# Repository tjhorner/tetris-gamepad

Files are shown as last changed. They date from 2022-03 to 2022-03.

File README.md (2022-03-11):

# Tetris Gamepad

These are the source files for an arcade-style gamepad designed for Tetris gameplay. Work in progress (things will break!)

**Disclaimer**: Tetris is a trademark of The Tetris Company, and I am not affiliated in any way with them. I'm just a fan of the game, and wanted to make this cool project for fun (and not profit). If you're a TTC lawyer and want me to rename this project, just let me know and I'll gladly do so. (No need to DMCA 😛)



## Directory Structure

- `src`: Source files for the firmware (licensed under MIT)
- `design`: PCB and enclosure design files (licensed under CC-BY-SA 4.0)
  - **Note:** The KiCad files may require you to install the [DigiKey library](https://forum.digikey.com/t/importing-the-digi-key-kicad-library-into-kicad-5-0-0/4075)

## Hardware

**License:** CC-BY-SA 4.0

This project is intended to be used with the [Adafruit HUZZAH32](https://www.adafruit.com/product/3405) board (mostly because that's what I had lying around), but with minor tweaks could be modified to use any ESP32 board, or even a raw ESP32 chip. The design is pretty simple; it just uses the GPIO pins in either `INPUT_PULLUP` mode (for the button inputs) or `OUTPUT` mode (for the button LEDs). Since it uses the `INPUT_PULLUP` mode, and the button LEDs have an inbuilt 200ohm resistor, no additional resistors are required.

If you want to build one yourself, here are the components you will need:

- 1x [Adafruit HUZZAH32](https://www.adafruit.com/product/3405)
- 8x [Arcade Button](https://www.adafruit.com/product/3491) (get creative with the colors!)
- 16x [Arcade Button Quick Connect Wire Pairs](https://www.adafruit.com/product/1152)
- 16x [B2B-XH-A JST Connector](https://www.digikey.com/en/products/detail/jst-sales-america-inc/B2B-XH-A-LF-SN/1651045)

You can find the KiCad files for the PCB design in the `design/pcb` directory, or if you want to quickly order some, here's a fancy button that will take you to the OSH Park page for the project:



## Enclosure

**License:** CC-BY-SA 4.0

The enclosure is a pretty simple box with fingers to assemble it, generated by [MakerCase](https://en.makercase.com/). There are holes in the top of the box that should fit the buttons snugly, along with some engravings near the buttons to indicate what they're for.

You can find the design files for the enclosure in the `design/enclosure` directory if you want to cut one out yourself.

## Firmware

**License:** MIT

The firmware development workflow is powered by [PlatformIO](https://platformio.org/), so you will need to get that set up if you want to modify or flash the firmware. All the dependencies are listed in the `platformio.ini` file so you shouldn't need to download anything manually.

### Operating Modes

The mode you are currently in will be indicated by how many times the startup animation loops (one cycle of the startup animation is all the LEDs turning on in order, then turning off).

- 1 time: gamepad mode
- 2 times: keyboard mode
- 3 times: Switch Pro Controller mode

You can switch between the modes by holding down a certain button during startup:

- HOLD: Switch to gamepad mode
- CCW: Switch to keyboard mode
- CW: Switch to Pro Controller mode

The default is gamepad mode. It will remember what mode you last selected on startup, so you don't need to hold the button down every time.

#### Gamepad Mode

In gamepad mode, the device will broadcast itself as a BLE gamepad. By default, the buttons are defined as such:

| **Physical Button** | **Virtual Button** |
|---|---|
| Hold | Button 0 |
| CCW | Button 1 |
| CW | Button 2 |
| Left | Button 3 |
| Right | Button 4 |
| Hard Drop | Button 5 |
| Soft Drop | Button 6 |
| Zone | Button 7 |

This does not follow a standard layout for e.g., an Xbox controller, so you will probably need to set up custom bindings in the game you are playing. You can also change the button assignments in the `modes/gamepad.h` file.

#### Keyboard Mode

In keyboard mode, the device will broadcast itself as a BLE keyboard. This mode is not as stable as gamepad or Pro Controller mode, so it should be used only as a backup method if those don't work.

The default bindings are:

| **Button** | **Key** |
|---|---|
| Hold | Left Shift  |
| CCW | Z |
| CW | X |
| Left | Left Arrow  |
| Right | Right Arrow |
| Hard Drop  | Space |
| Soft Drop  | Down Arrow  |
| Zone | A |

They follow normal the normal Guideline layout, so you should be fine with most games, but if you need to change them, you can do so in the `modes/keyboard.h` file.

#### Pro Controller Mode

Since the Switch does not support using generic Bluetooth gamepads, this is a special mode which imitates a Pro Controller.

**Note:** To use the gamepad with your Switch in Pro Controller mode, you will need to go to `Controllers > Change Grip/Order` every time you connect the controller. It's annoying, but I haven't figured out how to persist the pairing with the console.

The default bindings are:

| **Physical Button** | **Virtual Button** |
|---|---|
| Hold | L |
| CCW | B |
| CW | A |
| Left | D-Pad Left |
| Right | D-Pad Right |
| Hard Drop | D-Pad Up |
| Soft Drop | D-Pad Down |
| Zone | ZL |

Similar to the keyboard mode, these bindings also follow the Guideline layout, but can be changed in `modes/switch.h`.

### Configuration

If you want to modify which pins correspond to which buttons, you can do that in the `config.h` file. For convenience, `pins.h` defines a list of which JST connectors (labeled on the PCB) correspond to which GPIO pins (you can also modify this if need be).

You can also change which buttons you need to press to switch between modes.

There are a few other useful config options here as well; I'll document them eventually.

## Acknowledgements

Thanks to...

- The kind folks at [NYC Resistor](https://www.nycresistor.com/) for hosting their public craft nights, which opened up a bunch of resources and tools (namely, the laser cutter!) to me, helping make this project a reality
- The creator of [MakerCase](https://en.makercase.com/) for making laser cut boxes easy
- The creator of both the [ESP32 gamepad](https://github.com/lemmingDev/ESP32-BLE-Gamepad) and [ESP32 keyboard](https://github.com/T-vK/ESP32-BLE-Keyboard) libraries, which are basically the entire basis for the firmware
- The [BlueCubeMod](https://github.com/NathanReeves/BlueCubeMod) project, which is what the Pro Controller mode is largely based on

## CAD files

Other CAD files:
design/pcb/mount.blend

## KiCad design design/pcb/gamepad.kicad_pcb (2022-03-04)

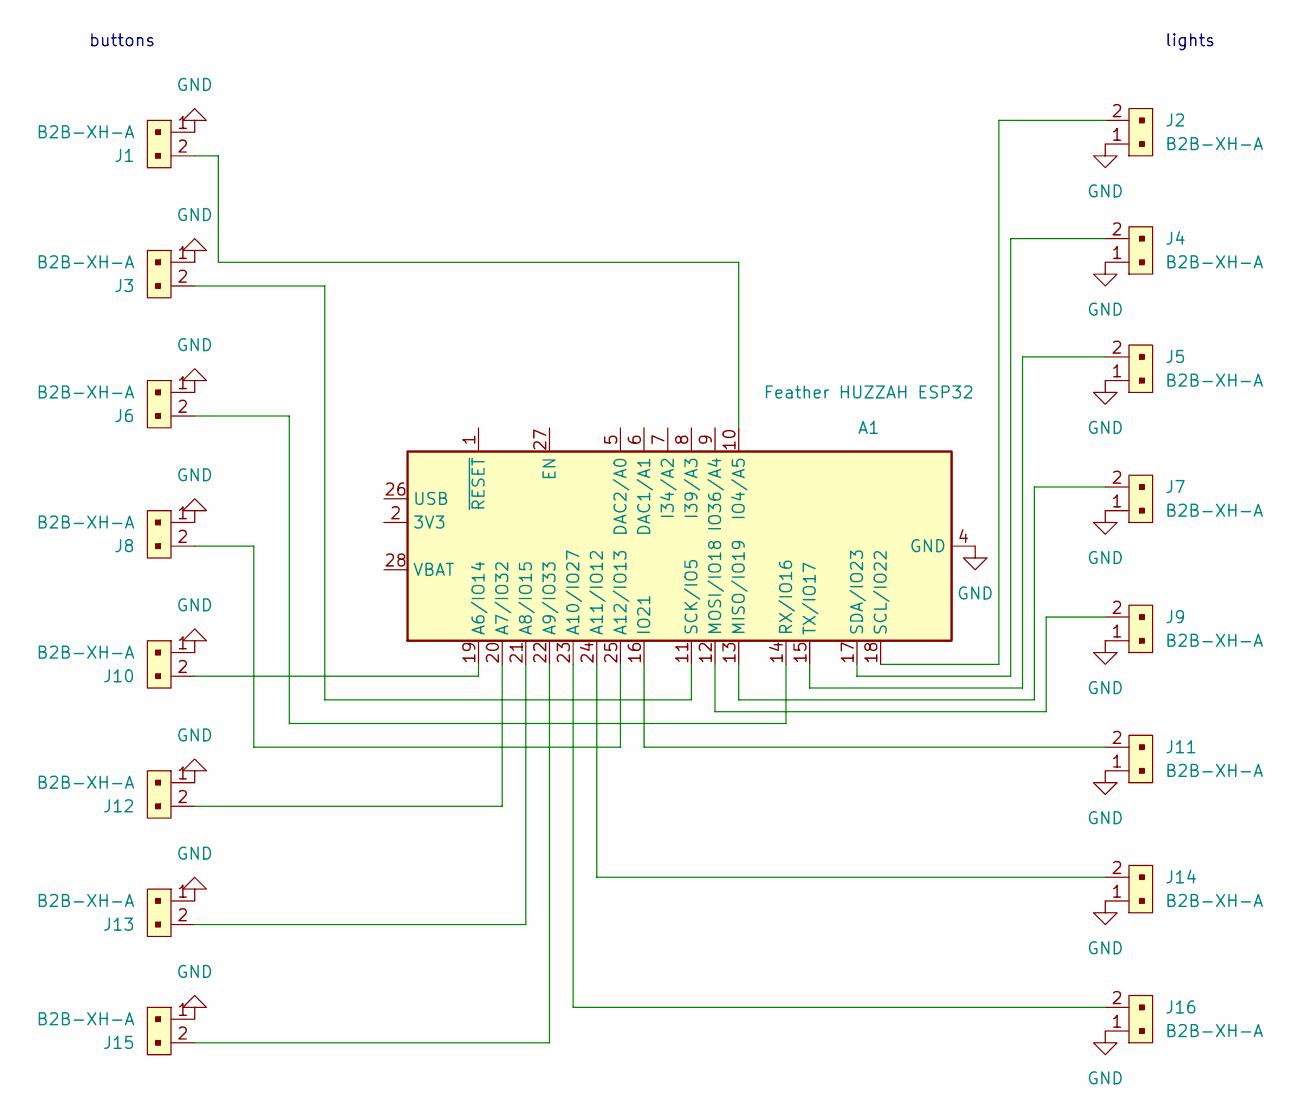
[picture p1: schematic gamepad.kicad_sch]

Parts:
A1: Feather HUZZAH ESP32; Adafruit_Feather
J1, J2, J3, J4, J5, J6, J7, J8, J9, J10, J11, J12, J13, J14, J15, J16: B2B-XH-A; PinHeader_1x2_P2.5mm_Drill1.1mm; MPN B2B-XH-A(LF)(SN); Digi-Key_PN 455-2247-ND

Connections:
GND: A1.4 (GND), J1.1, J2.1, J3.1, J4.1, J5.1, J6.1, J7.1, J8.1, J9.1, J10.1, J11.1, J12.1, J13.1, J14.1, J15.1, J16.1
unnamed: A1.10 (IO4/A5), J1.2
unnamed: A1.11 (SCK/IO5), J3.2
unnamed: A1.12 (MOSI/IO18), J9.2
unnamed: A1.13 (MISO/IO19), J7.2
unnamed: A1.14 (RX/IO16), J6.2
unnamed: A1.15 (TX/IO17), J5.2
unnamed: A1.16 (IO21), J11.2
unnamed: A1.17 (SDA/IO23), J4.2
unnamed: A1.18 (SCL/IO22), J2.2
unnamed: A1.19 (A6/IO14), J10.2
unnamed: A1.20 (A7/IO32), J12.2
unnamed: A1.21 (A8/IO15), J13.2
unnamed: A1.22 (A9/IO33), J15.2
unnamed: A1.23 (A10/IO27), J16.2
unnamed: A1.24 (A11/IO12), J14.2
unnamed: A1.25 (A12/IO13), J8.2

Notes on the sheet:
buttons
lights

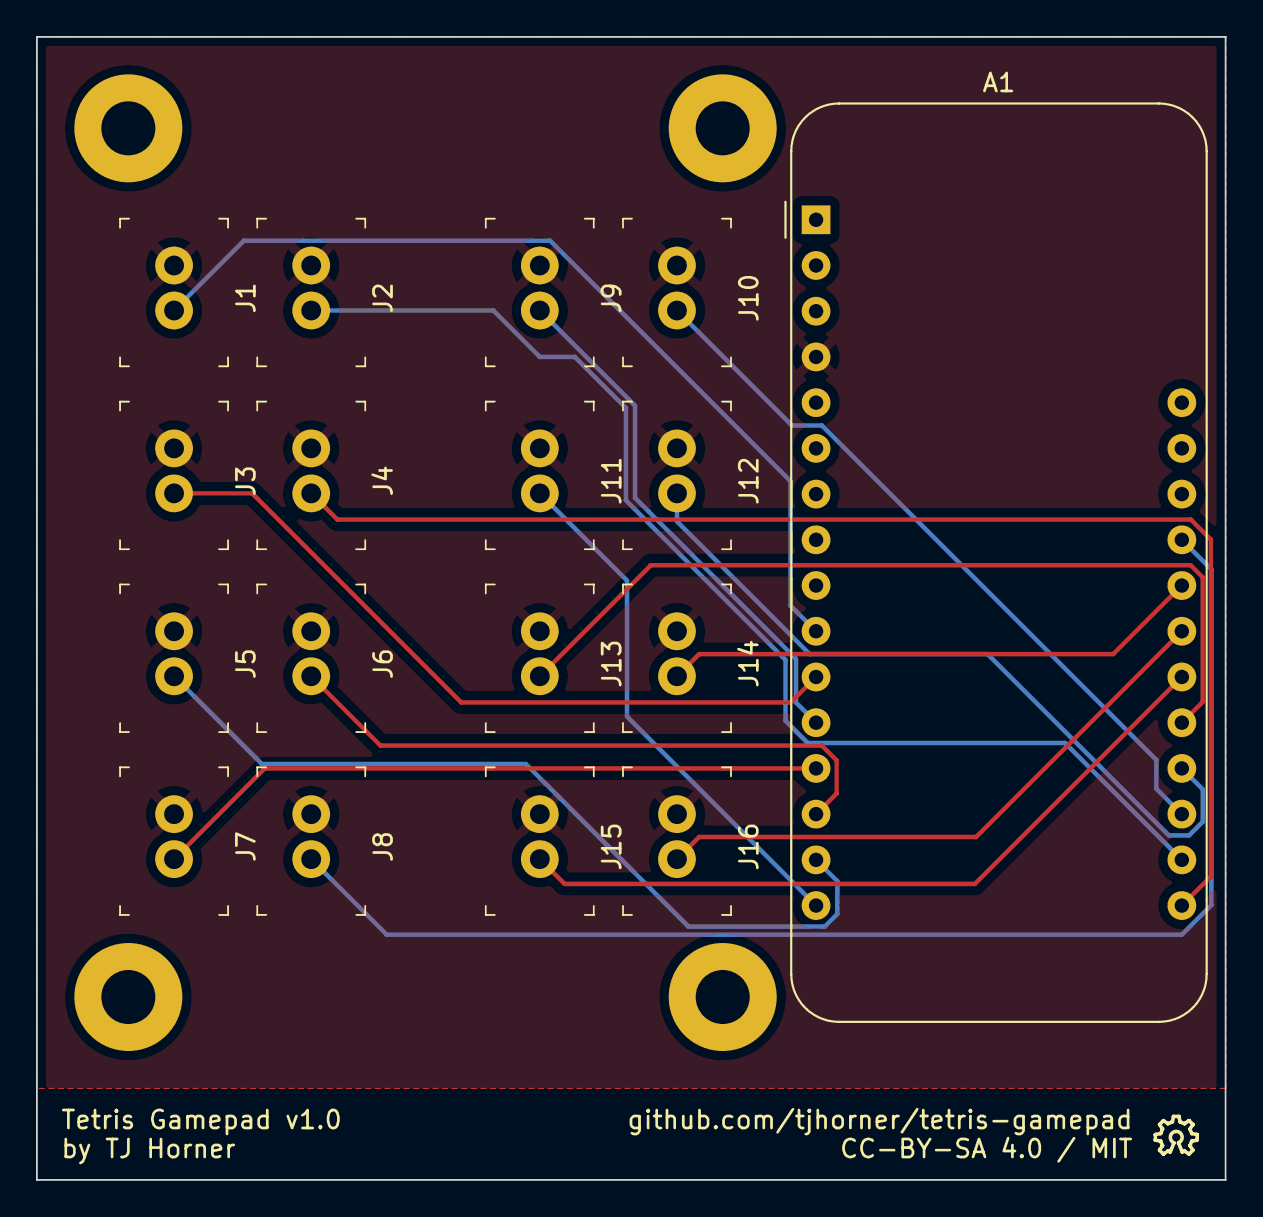
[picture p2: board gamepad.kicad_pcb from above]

Board: 2 copper layers, 66.0 x 63.5 mm, 21 parts (0 on the bottom side), 17 nets.

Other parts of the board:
MH1, MH2, MH3, MH4: MountingHole_3mm_Pad

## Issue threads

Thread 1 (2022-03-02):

Switch Pro Controller emulation

tjhorner, 2022-03-02:
This is a big one! I've done a bunch of research, and it looks like the easiest path forward is using the HID API from the ESP-IDF. However, in the PlatformIO Arduino ESP32 platform, that is disabled in the `sdkconfig`. So I will need to find some way to either compile my own or import the library directly.

Closed 2022-03-04.

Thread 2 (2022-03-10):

PCB v2 Wishlist

tjhorner, 2022-03-10:
Now that the first real, working prototype is complete, it's time to iterate and make v2 even better! I want to primarily focus on the PCB design, and make it more challenging for myself, while also making it cooler and easier to use.

- [ ] Raw ESP32-WROOM module — no dev boards here
- [ ] USB-C connector (this doesn't really provide any technical benefit, I just like USB-C better)
- [ ] Power switch
- [ ] Reset button
- [ ] USB HID module for wired communication? Need more research here

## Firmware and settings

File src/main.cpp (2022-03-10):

#include "main.h"

Mode* mode;
SemaphoreHandle_t mutex;

struct ButtonDefinition {
  ButtonType type;
  uint8_t inputPin;
  uint8_t ledPin;
  bool beingPressed;
};

ButtonDefinition buttonMap[] = {
  // Row 1
  { Hold, BUTTON_HOLD_INPUT, BUTTON_HOLD_LED },
  { CCW, BUTTON_CCW_INPUT, BUTTON_CCW_LED },
  { CW, BUTTON_CW_INPUT, BUTTON_CW_LED },
  { Left, BUTTON_LEFT_INPUT, BUTTON_LEFT_LED },
  { Right, BUTTON_RIGHT_INPUT, BUTTON_RIGHT_LED },

  // Row 2
  { HardDrop, BUTTON_HARD_DROP_INPUT, BUTTON_HARD_DROP_LED },
  { SoftDrop, BUTTON_SOFT_DROP_INPUT, BUTTON_SOFT_DROP_LED },

  // Row 3
  { Zone, BUTTON_ZONE_INPUT, BUTTON_ZONE_LED },
};

enum SelectedMode {
  Gamepad, // default, since it's first
  Keyboard,
  Switch
};

SelectedMode getSavedMode() {
  return (SelectedMode) EEPROM.read(ADDR_SAVED_MODE);
}

void setSavedMode(SelectedMode mode) {
  EEPROM.write(ADDR_SAVED_MODE, (uint8_t) mode);
  EEPROM.commit();
}

void startupAnimation(int repeatCount) {
  for (int i = 0; i < repeatCount; i++) {
    for (ButtonDefinition& btn : buttonMap) {
      digitalWrite(btn.ledPin, HIGH);
      vTaskDelay(50 / portTICK_PERIOD_MS);
    }

    vTaskDelay(100 / portTICK_PERIOD_MS);

    for (ButtonDefinition& btn : buttonMap) {
      digitalWrite(btn.ledPin, LOW);
      vTaskDelay(50 / portTICK_PERIOD_MS);
    }

    vTaskDelay(100 / portTICK_PERIOD_MS);
  }
}

extern "C" void app_main() {
  static const char* TAG = "app_main";

  initArduino();

  EEPROM.begin(EEPROM_SIZE);

  mutex = xSemaphoreCreateMutex();

  for (ButtonDefinition& btn : buttonMap) {
    btn.beingPressed = false;
    pinMode(btn.inputPin, INPUT_PULLUP);
    pinMode(btn.ledPin, OUTPUT);
  }

  // Set mode based on button held at startup (See config.h to customize)
  if (digitalRead(MODE_SELECT_GAMEPAD) == LOW) {
    ESP_LOGI(TAG, "Switching to gamepad mode");
    setSavedMode(Gamepad);
  } else if (digitalRead(MODE_SELECT_KEYBOARD) == LOW) {
    ESP_LOGI(TAG, "Switching to keyboard mode");
    setSavedMode(Keyboard);
  } else if (digitalRead(MODE_SELECT_SWITCH) == LOW) {
    ESP_LOGI(TAG, "Switching to Switch Pro Controller mode");
    setSavedMode(Switch);
  }

  switch (getSavedMode()) {
    default:
      // somehow got in an invalid state
      setSavedMode(Gamepad);
    case Gamepad:
      mode = new GamepadMode();
      startupAnimation(1);
      break;
    case Keyboard:
      mode = new KeyboardMode();
      startupAnimation(2);
      break;
    case Switch:
      mode = new SwitchMode();
      startupAnimation(3);
      break;
  }

  bool forceResetMac = digitalRead(RESET_MAC_INPUT) == LOW;
  setMacAddress((int) getSavedMode(), forceResetMac);

  assert(mode != NULL);
  mode->setup();

  while (true) {
    for (ButtonDefinition& btn : buttonMap) {
      bool pressed = digitalRead(btn.inputPin) == LOW;
      if (pressed != btn.beingPressed) {
        btn.beingPressed = pressed;

        if (pressed) {
          assert(mode != NULL);
          mode->pressButton(btn.type);
          digitalWrite(btn.ledPin, HIGH);
        } else {
          assert(mode != NULL);
          mode->releaseButton(btn.type);
          digitalWrite(btn.ledPin, LOW);
        }
      }
    }

    vTaskDelay(15 / portTICK_PERIOD_MS);
  }
}

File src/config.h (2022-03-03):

#ifndef CONFIG_H
#define CONFIG_H

// Pin to button map
#define BUTTON_HOLD_INPUT J1
#define BUTTON_HOLD_LED J2

#define BUTTON_CCW_INPUT J3
#define BUTTON_CCW_LED J4

#define BUTTON_CW_INPUT J5
#define BUTTON_CW_LED J6

#define BUTTON_LEFT_INPUT J7
#define BUTTON_LEFT_LED J8

#define BUTTON_RIGHT_INPUT J9
#define BUTTON_RIGHT_LED J10

#define BUTTON_HARD_DROP_INPUT J11
#define BUTTON_HARD_DROP_LED J12

#define BUTTON_SOFT_DROP_INPUT J13
#define BUTTON_SOFT_DROP_LED J14

#define BUTTON_ZONE_INPUT J15
#define BUTTON_ZONE_LED J16

// Buttons to hold during startup to select a mode
#define MODE_SELECT_GAMEPAD BUTTON_HOLD_INPUT
#define MODE_SELECT_KEYBOARD BUTTON_CCW_INPUT
#define MODE_SELECT_SWITCH BUTTON_CW_INPUT
#define RESET_MAC_INPUT BUTTON_ZONE_INPUT

#define EEPROM_SIZE 16
#define ADDR_SAVED_MODE 0
#define ADDR_BASE_ADDRESS 1

#define EXTRA_LOGS 0

#endif

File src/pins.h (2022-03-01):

#ifndef PINS_H
#define PINS_H

#define J1 4
#define J2 22
#define J3 5 // outputs PWM signal at boot
#define J4 23
#define J5 17
#define J6 16
#define J7 19
#define J8 13
#define J9 18
#define J10 14 // outputs PWM signal at boot
#define J11 21
#define J12 32
#define J13 15 // outputs PWM signal at boot
#define J14 12 // boot fail if pulled high (using for LED, so that's fine)
#define J15 33
#define J16 27

#endif

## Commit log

2022-03-01 some updates
    [gamepad.kicad_pcb, gamepad.kicad_sch]
2022-03-01 update traces
    [gamepad.kicad_pcb]
2022-03-01 firmware update, fix an oopsie in the pcb
    [gamepad.kicad_pcb, gamepad.kicad_sch, mount.blend]
2022-03-02 switch pro controller kinda
2022-03-02 use unique MAC per mode
    [mount.blend]
2022-03-03 working Switch mode
2022-03-03 note about switch mode
2022-03-03 switch to ESP-IDF entrypoint, stuff to make latency better
2022-03-03 re-enable LED stuffs
2022-03-04 switch away from interrupts, that appears to be faster
    [gamepad.kicad_pcb]
2022-03-10 migrate logging to ESP logging library to keep things consistent
    [mount.blend]

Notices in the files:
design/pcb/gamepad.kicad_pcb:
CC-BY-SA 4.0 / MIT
